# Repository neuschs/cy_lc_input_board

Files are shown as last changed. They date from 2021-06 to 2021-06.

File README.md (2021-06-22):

# cy_lc_input_board
Input Protection Board for "Lcsoft CY7C68013A Mini Board"

# Protections

- Input Buffer via 74HC241 or 74HC244 (switchable via Jumper [Output Enables])
- ESD Protection via ESDA6V1L (Didnt choose bigger diode array for signal path reasons) Not necessary but neat.
- Switchable 4,7V Zener Diodes for signals greater than 5V eg 24V. | Series Resistors for current limitation of zener diodes
- Additional USB B port for full enclosure (needs to be hand soldered to the usb footprint of the cypress board)
- External power connector for "expansion" boards. 

# Todo
- Design enclosure
- Add LEDs to the IO header and solder them to the old leds on the cypress board for diagnostic purposes

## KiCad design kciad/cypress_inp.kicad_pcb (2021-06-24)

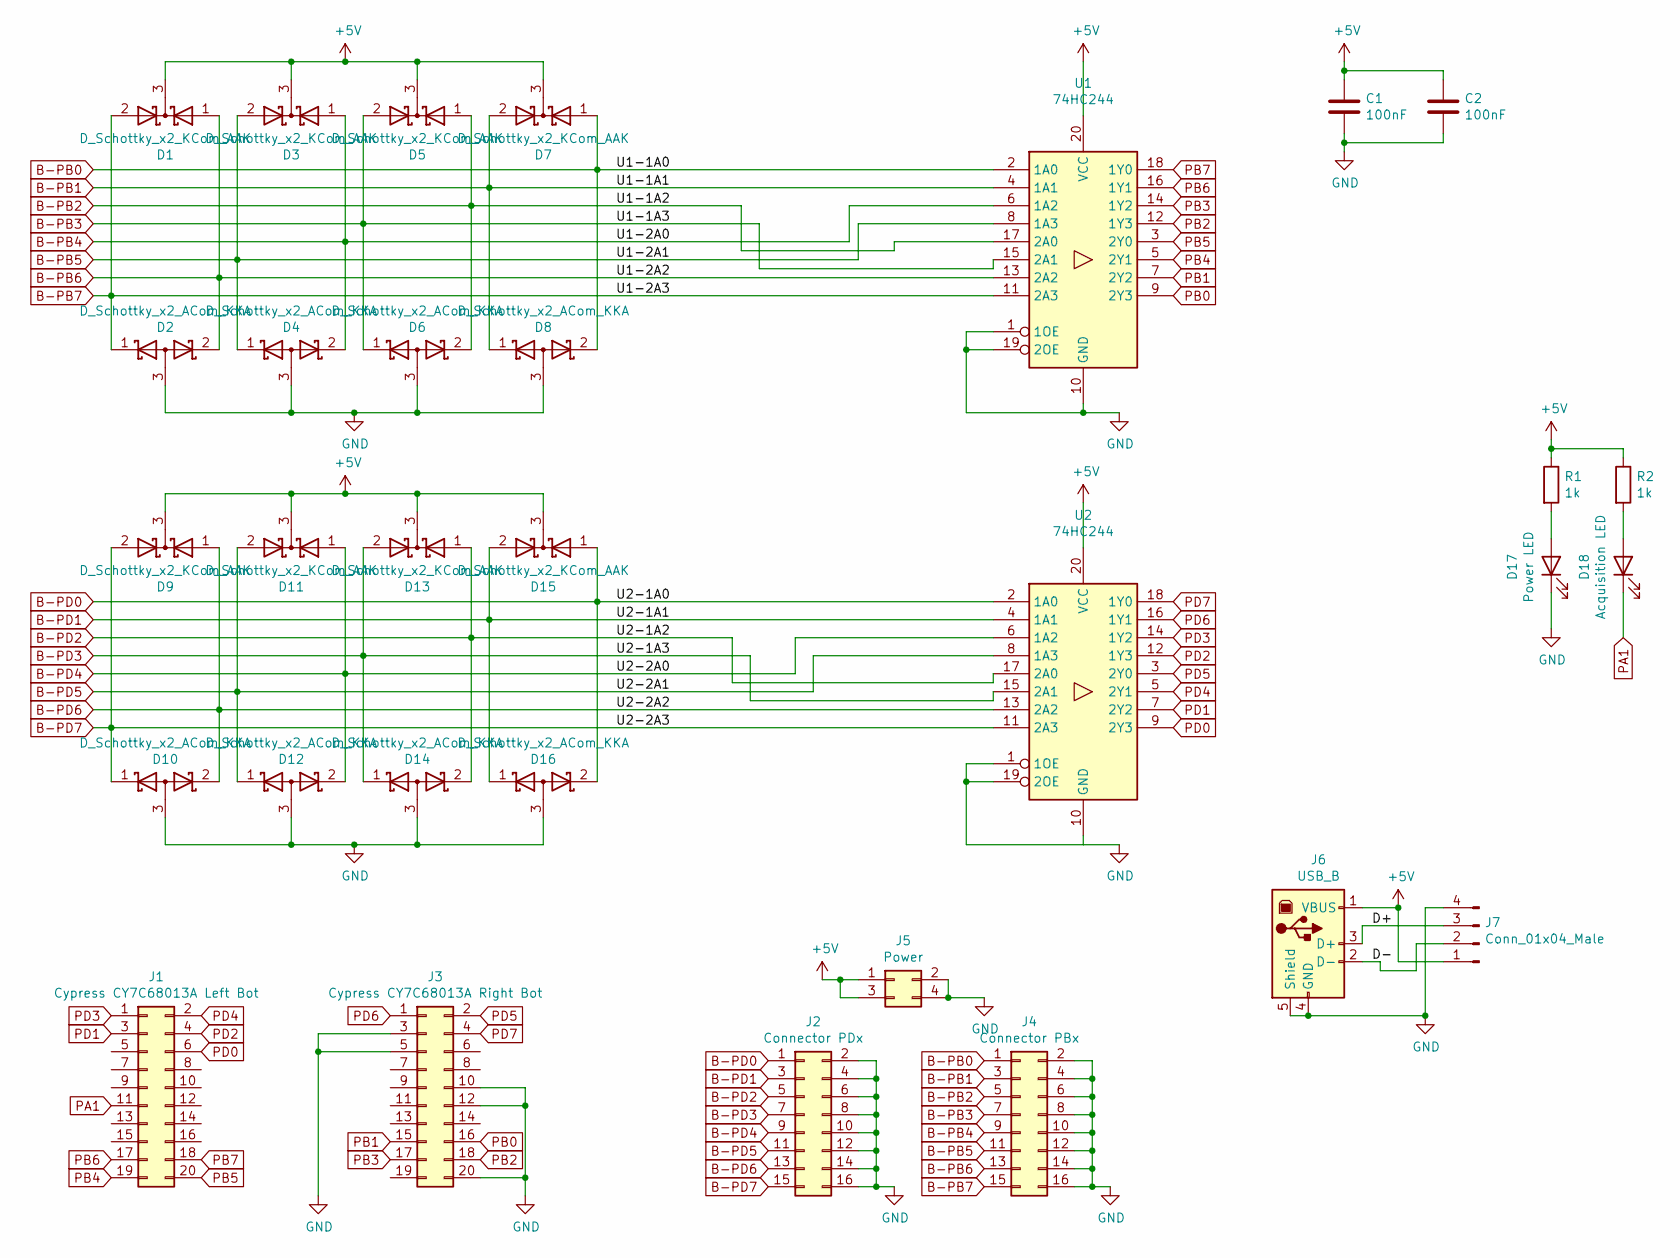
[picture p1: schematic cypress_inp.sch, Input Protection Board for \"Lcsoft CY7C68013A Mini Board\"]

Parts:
C1, C2: 100nF; C_1206_3216Metric_Pad1.33x1.80mm_HandSolder
D1, D3, D5, D7, D9, D11, D13, D15: D_Schottky_x2_KCom_AAK; SOT-23_Handsoldering
D2, D4, D6, D8, D10, D12, D14, D16: D_Schottky_x2_ACom_KKA; SOT-23_Handsoldering
D17: Power LED; LED_D3.0mm
D18: Acquisition LED; LED_D3.0mm
J1: Cypress CY7C68013A Left Bot; PinSocket_2x10_P2.54mm_Vertical
J2: Connector PDx; PinSocket_2x08_P2.54mm_Horizontal
J3: Cypress CY7C68013A Right Bot; PinSocket_2x10_P2.54mm_Vertical
J4: Connector PBx; PinSocket_2x08_P2.54mm_Horizontal
J5: Power; PinSocket_2x02_P2.54mm_Horizontal
J6: USB_B; USB_B_TE_5787834_Vertical
J7: Conn_01x04_Male; PinHeader_1x04_P2.54mm_Vertical
R1, R2: 1k; R_1210_3225Metric_Pad1.30x2.65mm_HandSolder
U1, U2: 74HC244; SO-20_5.3x12.6mm_P1.27mm

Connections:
+5V: C1.1, C2.1, D1.3 (K), D3.3 (K), D5.3 (K), D7.3 (K), D9.3 (K), D11.3 (K), D13.3 (K), D15.3 (K), J5.1, J5.3, J6.1 (VBUS), J7.1, R1.1, R2.1, U1.20 (VCC), U2.20 (VCC)
/D+: J6.3 (D+), J7.3
/D-: J6.2 (D-), J7.2
B-PB0: D7.1 (A), D8.2 (K), J4.1, U1.2 (1A0)
B-PB1: D7.2 (A), D8.1 (K), J4.3, U1.4 (1A1)
B-PB2: D5.1 (A), D6.2 (K), J4.5, U1.17 (2A0)
B-PB3: D5.2 (A), D6.1 (K), J4.7, U1.15 (2A1)
B-PB4: D3.1 (A), D4.2 (K), J4.9, U1.6 (1A2)
B-PB5: D3.2 (A), D4.1 (K), J4.11, U1.8 (1A3)
B-PB6: D1.1 (A), D2.2 (K), J4.13, U1.13 (2A2)
B-PB7: D1.2 (A), D2.1 (K), J4.15, U1.11 (2A3)
B-PD0: D15.1 (A), D16.2 (K), J2.1, U2.2 (1A0)
B-PD1: D15.2 (A), D16.1 (K), J2.3, U2.4 (1A1)
B-PD2: D13.1 (A), D14.2 (K), J2.5, U2.17 (2A0)
B-PD3: D13.2 (A), D14.1 (K), J2.7, U2.15 (2A1)
B-PD4: D11.1 (A), D12.2 (K), J2.9, U2.6 (1A2)
B-PD5: D11.2 (A), D12.1 (K), J2.11, U2.8 (1A3)
B-PD6: D9.1 (A), D10.2 (K), J2.13, U2.13 (2A2)
B-PD7: D9.2 (A), D10.1 (K), J2.15, U2.11 (2A3)
GND: C1.2, C2.2, D2.3 (A), D4.3 (A), D6.3 (A), D8.3 (A), D10.3 (A), D12.3 (A), D14.3 (A), D16.3 (A), D17.1 (K), J2.2, J2.4, J2.6, J2.8, J2.10, J2.12, J2.14, J2.16, J3.3, J3.5, J3.10, J3.12, J3.20, J4.2, J4.4, J4.6, J4.8, J4.10, J4.12, J4.14, J4.16, J5.2, J5.4, J6.4 (GND), J6.5 (Shield), J7.4, U1.1 (1OE), U1.10 (GND), U1.19 (2OE), U2.1 (1OE), U2.10 (GND), U2.19 (2OE)
unnamed: D17.2 (A), R1.2
unnamed: D18.2 (A), R2.2
PA1: D18.1 (K), J1.11
PB0: J3.16, U1.9 (2Y3)
PB1: J3.15, U1.7 (2Y2)
PB2: J3.18, U1.12 (1Y3)
PB3: J3.17, U1.14 (1Y2)
PB4: J1.19, U1.5 (2Y1)
PB5: J1.20, U1.3 (2Y0)
PB6: J1.17, U1.16 (1Y1)
PB7: J1.18, U1.18 (1Y0)
PD0: J1.6, U2.9 (2Y3)
PD1: J1.3, U2.7 (2Y2)
PD2: J1.4, U2.12 (1Y3)
PD3: J1.1, U2.14 (1Y2)
PD4: J1.2, U2.5 (2Y1)
PD5: J3.2, U2.3 (2Y0)
PD6: J3.1, U2.16 (1Y1)
PD7: J3.4, U2.18 (1Y0)

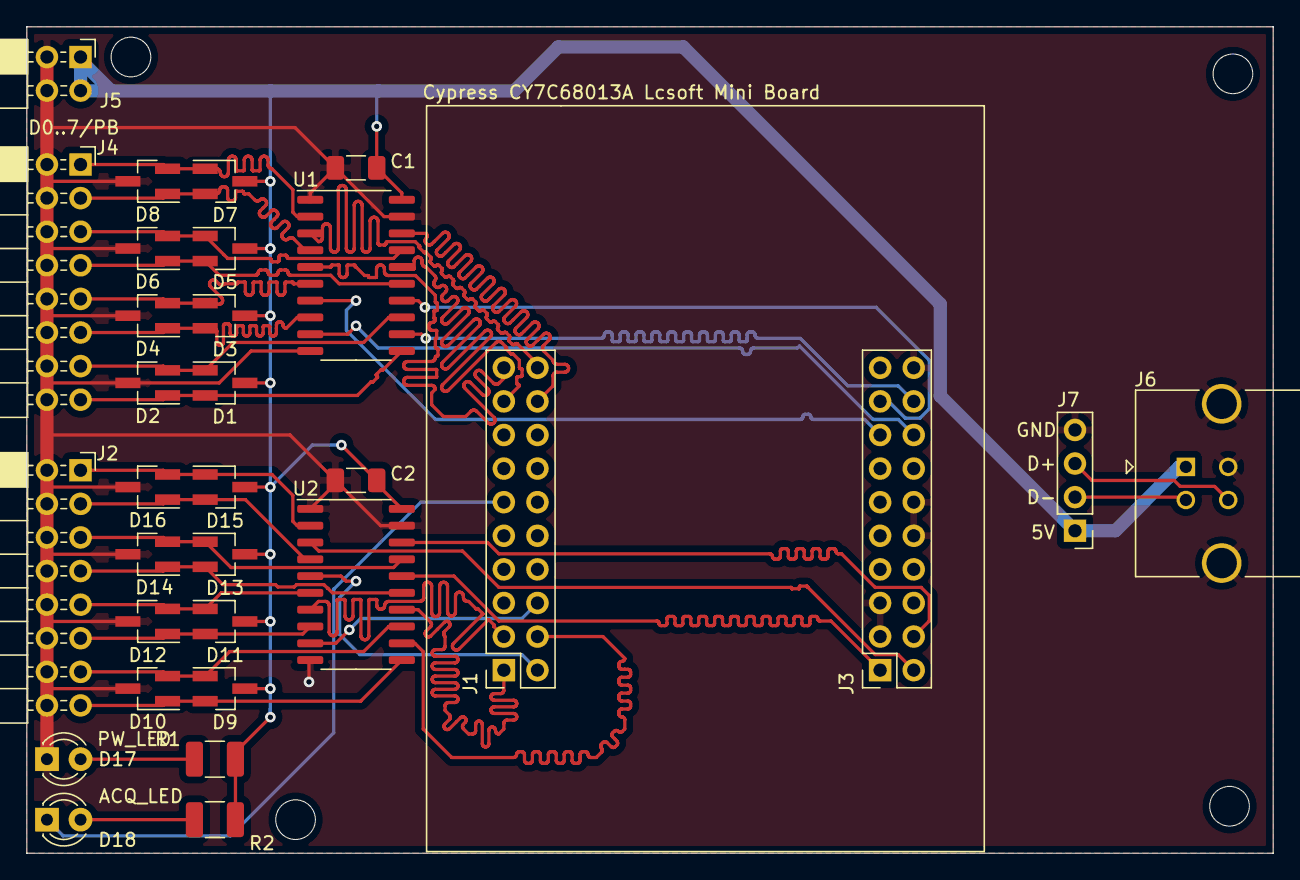
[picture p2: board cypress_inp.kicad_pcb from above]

Board: 2 copper layers, 94.2 x 62.5 mm, 31 parts (0 on the bottom side), 39 nets.

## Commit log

2021-06-20 * initial commit, pcb is almost done
    [cypress_inp.kicad_pcb, cypress_inp.sch]
2021-06-22 * changed layout so signal paths are shorter
    [cypress_inp.kicad_pcb]
2021-06-23 * changed whole schematic and pcb layout
    [cypress_inp.kicad_pcb, cypress_inp.sch]
2021-06-24 * added gerber files, * copleted routing of pcb
    [cypress_inp-B_Cu.gbl, cypress_inp-B_Mask.gbs, cypress_inp-B_Paste.gbp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]
